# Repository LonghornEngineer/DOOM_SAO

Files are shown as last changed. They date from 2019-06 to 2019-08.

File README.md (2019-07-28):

### DOOM Shitty Add On Features
***
**Add on for conference badges that features a LCD Screen and DOOM Guy.**

The DOOM Shitty Add On (DOOM SAO) is an add on for conference badges that implement the [V1.69bis standard](https://hackaday.com/2019/03/20/introducing-the-shitty-add-on-v1-69bis-standard/) for SAO devices. Additionally, it has provisions to be a full on development platform for the ATSAMD21G18A microcontroller. The MCU and preinstalled bootloader are also Arduino compatible to aid in the ease of hardware and firmware hacking. This document will explain the feature set and how to interface with the DOOM SAO to bring out its full potential.

Doom SAO

## Full Feature Set
* Arduino Compatible MCU ATSAMD21G18A
* All unused I/O from the MCU is accessible
* Full implementation of the [V1.69bis standard](https://hackaday.com/2019/03/20/introducing-the-shitty-add-on-v1-69bis-standard/)
* Auto mode for DOOM Guy for badges that are not DOOM SAO compatible
* Serial Terminal accessible through the USB Type-C connector
* Passive Hardware Bus Sniffing
* User defined section for adding your own code
* High DPI ST7789 1.3" 240x240 LCD Screen
* USB Type-C configured for USB 2.0 (REVERSIBLE)

## Interfacing with the DOOM SAO via Serial UART

Connection Settings: 9600/8/N/1

Ensure your terminal terminates with Carriage Return (The Arduino Serial Monitor defaults to New Line. This is wrong)

Press 'X' to start the interactive menu.

Press 1..6 to select sub-menu options.

Press 'Q' within any sub-menu to quit to the main menu.

Menu Options:

1 - DOOM Guy Interface Mode
This allows you to modify the EEPROM directly to dynamically control the animations and SAO behavior.

2 - DOOM Guy Bus Sniffer Mode
This is a filtered view of the DOOM Guy's I2C traffic. It's a poor man's logic analyzer, decoded for SAO interpretation.

3 - I2C Bus Sniffer Mode
This allows you to monitor the entire I2C bus. If a host has more than one SAO port you can see what magic bytes and data other SAO's are transmitting in addtion to what the badge is using on I2C. It's a poor man's logic analyzer, decoded in general, for seeing I2C NACK, ACK, Reads, and Writes.

4 - Serial UART Sniffer Mode
This allows you to passively man in the middle another embedded system's serial UART line. 
Connect the source's serial TX to the SAO RX Pin PB23.
Connect the target's serial RX to the SAO TX Pin PB22.
Choose the appropriate baud rate and byte translation (ASCII or DEC).

5 - Custom  Application Mode
This is the area for YOU to add your own code.

6 - EEPROM Persistance Mode
This allows you to save changes made to the EEPROM, which by default reset on power cycle.

6 - BADGE SAO Airplane Mode
This allows you to ignore all logical control of the host badge. In minor cases, a badge may have a component which uses the same address (0x50) as our SAO, which will result in unexpected behavior. This is known to be the case with Team Ides DaBomb! Badge. In this case, enable persistance, enable airplane mode, then disable persistance so the SAO can still operate in a standalone mode. Not doing so will require reflashing of the SAO with the Arduino IDE.

## Interfacing with the DOOM SAO via I2C

The DOOM SAO implements the [V1.69bis standard](https://hackaday.com/2019/03/20/introducing-the-shitty-add-on-v1-69bis-standard/) for SAO devices and follows the [AND!XOR SAO Reference Design](https://github.com/ANDnXOR/sao-reference-designs). What this means is that using the I2C interface and GPIO pins of the V1.69bis standard users will be able to control how DOOM Guy acts and behaves.

The I2C address for DOOM SAO is 0x50. This is the standard address for the I2C AT24C32 EEPROM. Over the I2C interface, DOOM SAO acts like a simulated EEPROM. Only single byte reads and writes are supported. Attempting to do multi byte reads or writes are not implemented at this time. For identification purposes the first 3 address locations are used. See the [AND!XOR SAO Reference Design](https://github.com/ANDnXOR/sao-reference-designs) for more information. Below is the EEPROM address structure. 

| 0		| 1		| 2 	| 3...n	|
|:-:	|:-:	|:-:	|:-:	|
| 0x1B	| 0x05	| 0x01	| Data	|

* Address 0 is the DC Year. Use 0x1B for DC27.
* Address 1 is my Maker ID which is a unique identifier for SAO maker, I chose 0x05 at random for my maker ID. I do not know if there is a list of these ¯\_(ツ)_/¯.
* Address 2 is the SAO Type ID which is a unique identifier for the SAO. DOOM SAO is my only SAO so it is 0x01. 
* Addresss 3..n is where you can write stuff to the SAO!

First 3 addresses are protected and can not be overwritten unless you change them in the firmware and reflash the MCU.

### EEPROM Addresses

| Address	| Content	| Default Value	| Protected?	|
|:-:		|:-:		|:-:			|:-:			|
| 0x00		| DC Year	| 0x1B			| Yes			|
| 0x01		| Maker ID	| 0x05			| Yes			|
| 0x02		| SAO ID	| 0x01			| Yes			|
| 0x03		| AutoMode	| 0x01			| No			|
| 0x04		| Health	| 0x64			| No			|
| 0x05		| Anger	| 0x00			| No			|

### EEPROM functionality (quirks to note) 

Write functions to the DOOM SAO will always ACK regardless if you where successful or not in writing to that address location.
Reading data locations that do not exist will return with data 0x00. 

### What is Auto Mode?

When first booted up, DOOM SAO defaults to an auto mode. In this mode, Doom Guy looks left and right in an alternating manner with no control from the Badge. Writing a 0x00 value to this address disables auto mode and allows the GPIO to control DOOM Guy. With auto mode disabled, GPIO 1 makes DOOM Guy look left and GPIO 2 makes DOOM Guy look right. Truth table below.

| GPIO 1	| GPIO 2	| What Happens?			|
|:-:		|:-:		|:-:					|
| 0			| 0			| DG Looks Forward		|
| 1			| 0			| DG Looks Left			|
| 0			| 1			| DG Looks Right		|
| 1			| 1			| DG Looks Backwards	|

### What is Health?

The more "damage" Doom Guy takes the more beat up he becomes. Writing a value under 0x64 (100HP) will make Doom Guy look more bloody like he has been punched by a couple of demons. 

### What is Anger?

When Doom Guy gets pissed he gets pissed. Writing a 0x01 value to this location will seriously piss Doom Guy off. This must be his special spot. 

***
**License Information**

PROPRIETARY AND CONFIDENTIAL UNTIL AUGUST 11th, 2019 then,
Licensed under the Apache License, Version 2.0 (the "License");
you may not use this file except in compliance with the License.
You may obtain a copy of the License at
 
http://www.apache.org/licenses/LICENSE-2.0
 
Unless required by applicable law or agreed to in writing, software
distributed under the License is distributed on an "AS IS" BASIS,
WITHOUT WARRANTIES OR CONDITIONS OF ANY KIND, either express or implied.
See the License for the specific language governing permissions and
limitations under the License.
 
***

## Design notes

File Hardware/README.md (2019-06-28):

### DOOM Shitty Add On Hardware
***
**Add on for conference badges that features a LCD Screen and DOOM Guy.**

PCB was designed in AutoDesk Eagle V9.3+

## Hardware Specifications
* Arduino Compatible MCU ATSAMD21G18A
* Full implementation of the [V1.69bis standard](https://hackaday.com/2019/03/20/introducing-the-shitty-add-on-v1-69bis-standard/)
* High DPI ST7789 1.3" 240x240 LCD Screen
* USB Type-C configured for USB 2.0 (REVERSIBLE)
* TPS2113ADRBR Power Mux to prevent voltage back feed onto badge when USB power applied
* Tag Connect for ATMEL SWD Programming
* Unused GPIO from MCU broken out to headers
* Possibly the only 4 Layer SAO

## PCB Layers
1. Component mounting and signals
2. Ground
3. +3.3V
4. GPIO Breakout signals

## Schematic

Schematic DOOM SAO

## Board Layout

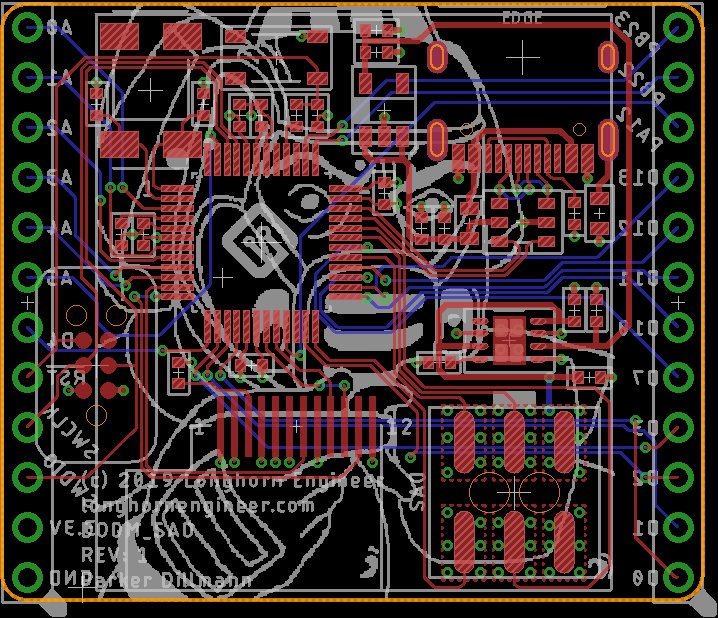
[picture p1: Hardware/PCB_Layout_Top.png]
Board Layout Top DOOM SAO


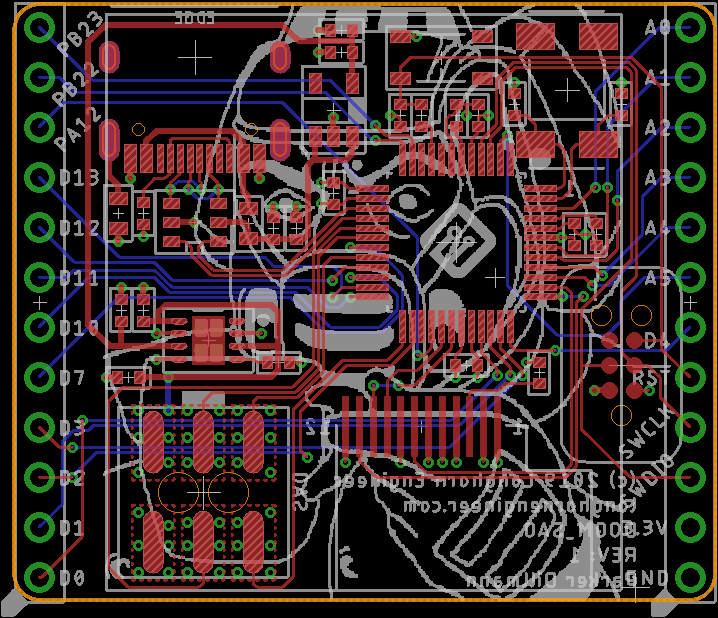
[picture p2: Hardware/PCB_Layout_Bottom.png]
Board Layout Bottom DOOM SAO


## PCB Render

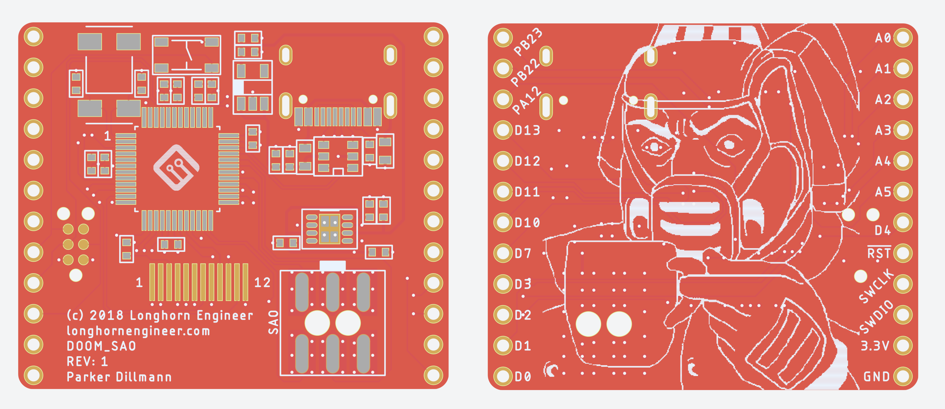
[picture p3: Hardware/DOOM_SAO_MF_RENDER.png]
PCB Render DOOM SAO


***
**License Information**

This project is under the [Creative Commons Attribution-ShareAlike 4.0 International License](LICENSE.md). These files are provided with no warranty and should be used at your own risk. 

***

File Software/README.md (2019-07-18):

### DOOM Shitty Add On Software 
***
**Add on for conference badges that features a LCD Screen and DOOM Guy.**

Software is written using the Arduino IDE 1.8.9. This document will explain how to setup the software environment to compile the firmware.

## Arduino Hardware Settings
* Board Manager Package: Arduino SAMD Boards (32-bits ARM Cortex-M0+) Version 1.8.2
* Board: Arduino M0

## Libraries
The following libraries need to be installed. These can be found through the Arduino Library Manager.

* Adafruit GFX Library Version 1.5.6
* Adafruit ST7735 and ST7789 Library Version 1.3.7
* Adafruit Zero DMA Library Version 1.0.4

## Modifying Libraries

To make these libraries work with the DOOM SAO Hardware some modifications must be made. 

In Windows these are located under *Documents\Arduino\libraries* if they were installed through the Arduino Library Manager.

In Ubuntu Linux these are located under *$HOME/Arduino/libraries* if they were installed through the Arduino Library Manager.

### Enabling SPI_MODE3
Since the hardware does not use the CS pin on the LCD we must change the GFX library from using SPI_MODE0 to SPI_MODE3. 

Open the *\Adafruit_GFX_Library\Adafruit_SPITFT.h* file
Change SPI_MODE0 in line 193 to SPI_MODE3
Save the file

Open the *\Adafruit_ST7735_and_ST7789_Library\Adafruit_ST7789.h* file
Change SPI_MODE0 in line 17 to SPI_MODE3
Save the file

### Enable DMA
In the GFX library the hardware DMA is not enabled by default and must be turned on.

Open the *\Adafruit_GFX_Library\Adafruit_SPITFT.h* file.
Uncomment Line 77 which reads *#define USE_SPI_DMA               ///< If set, use DMA if available*
Save the file

The DOOM_SAO.ino file should compile correctly in the Arduino IDE now. 

***

**License Information**

PROPRIETARY AND CONFIDENTIAL UNTIL AUGUST 11th, 2019 then,
Licensed under the Apache License, Version 2.0 (the "License");
you may not use this file except in compliance with the License.
You may obtain a copy of the License at
 
http://www.apache.org/licenses/LICENSE-2.0
 
Unless required by applicable law or agreed to in writing, software
distributed under the License is distributed on an "AS IS" BASIS,
WITHOUT WARRANTIES OR CONDITIONS OF ANY KIND, either express or implied.
See the License for the specific language governing permissions and
limitations under the License.
 
***

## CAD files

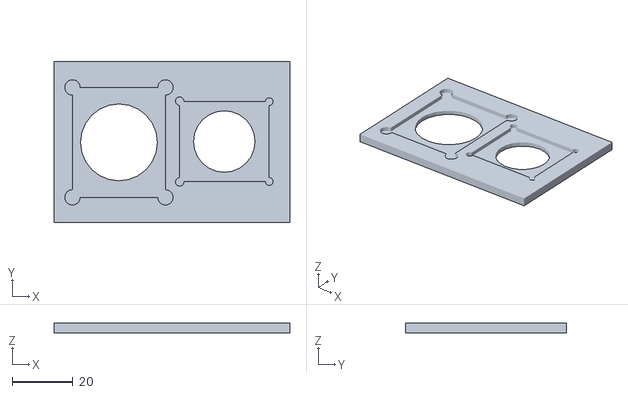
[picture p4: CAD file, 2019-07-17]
Hardware/Soldering_Fixture.stl
78.0 x 53.3 x 3.17

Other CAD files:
Hardware/Soldering_Fixture.skp

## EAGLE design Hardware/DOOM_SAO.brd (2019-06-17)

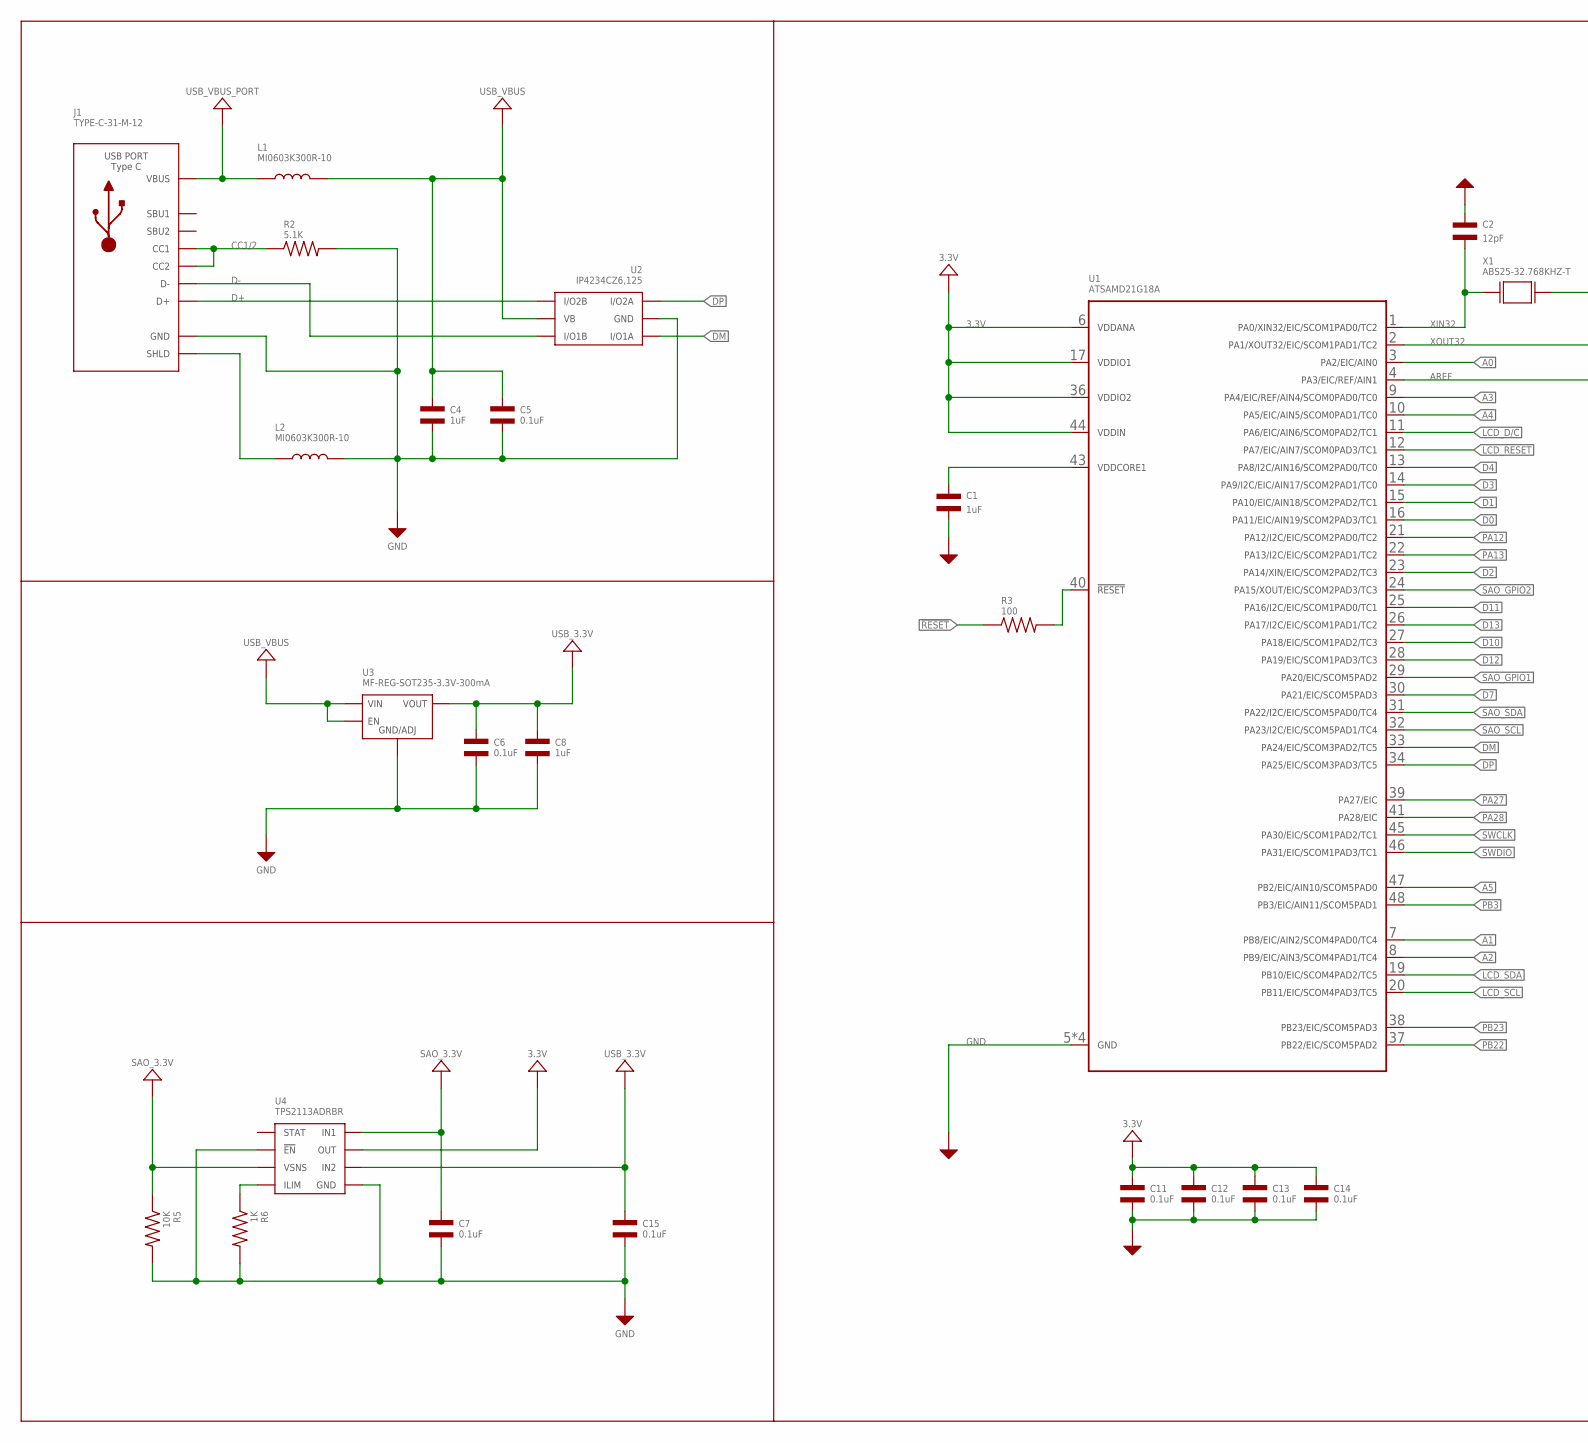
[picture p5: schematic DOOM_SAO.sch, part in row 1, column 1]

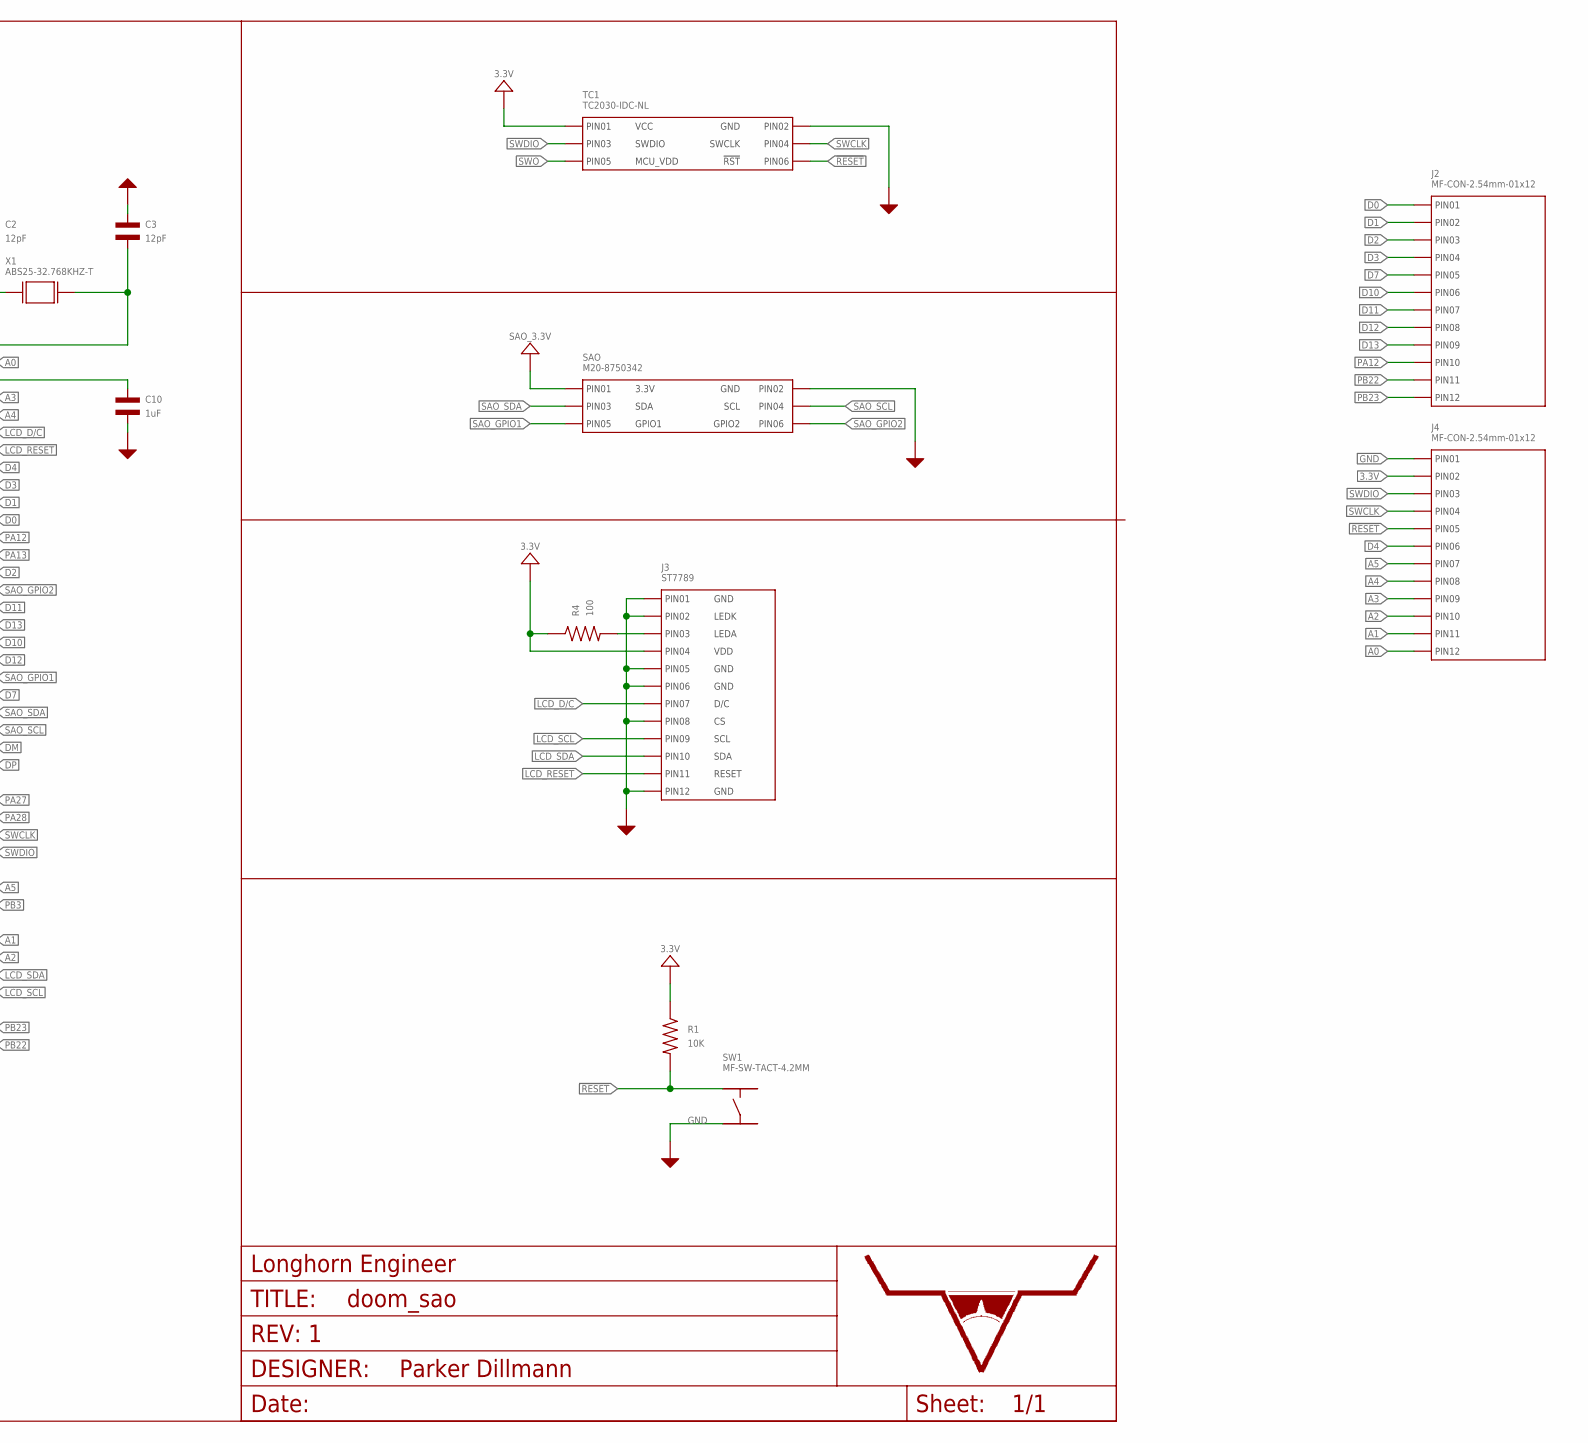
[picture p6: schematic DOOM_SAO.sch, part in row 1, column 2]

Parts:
C1, C4, C8, C10: 1uF; C0402; MPN MF-CAP-0402-1uF
C2, C3: 12pF; C0402; MPN CC0402JRNPO9BN120
C5, C6, C7, C11, C12, C13, C14, C15: 0.1uF; C0402; MPN MF-CAP-0402-0.1uF
J1: TYPE-C-31-M-12; MPN TYPE-C-31-M-12
J2, J4: MF-CON-2.54mm-01x12; PTH_2.54MM_01X12
J3: ST7789; ST7789_CONNECTOR
L1, L2: MI0603K300R-10; L0603; MPN MI0603K300R-10
R1, R5: 10K; R0402; MPN MF-RES-0402-10K
R2: 5.1K; R0402; MPN ERJ-2RHD5101X
R3, R4: 100; R0402; MPN MF-RES-0402-100
R6: 1K; R0402; MPN MF-RES-0402-1K
SAO: M20-8750342; MPN M20-8750342
SW1: MF-SW-TACT-4.2MM; TACT4.2MM
TC1: TC2030-IDC-NL
U1: ATSAMD21G18A; ATSAMD21G18A_TQFP-48; MPN ATSAMD21G18A-AU
U2: IP4234CZ6,125; IP4234CZ6_SOT-457-6; MPN IP4234CZ6,125
U3: MF-REG-SOT235-3.3V-300mA; SOT-23-5
U4: TPS2113ADRBR; TPS211X_SON-8
U$8: LHE_FRAME
X1: ABS25-32.768KHZ-T; ABS25_SERIES; MPN ABS25-32.768KHZ-T

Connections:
3.3V: C11.P$1, C12.P$1, C13.P$1, C14.P$1, J3.P$4 (4), J4.P$2 (PIN2), R1.P$1, R4.P$1, TC1.P$1 (PIN1), U1.6 (VDDANA), U1.17 (VDDIO1), U1.36 (VDDIO2), U1.44 (VDDIN), U4.7 (OUT)
!RESET: J4.P$5 (PIN5), R1.P$2, R3.P$1, SW1.P$1, TC1.P$6 (PIN6)
A0: J4.P$12 (PIN12), U1.3 (PA2/EIC/AIN0)
A1: J4.P$11 (PIN11), U1.7 (PB8/EIC/AIN2/SCOM4PAD0/TC4)
A2: J4.P$10 (PIN10), U1.8 (PB9/EIC/AIN3/SCOM4PAD1/TC4)
A3: J4.P$9 (PIN9), U1.9 (PA4/EIC/REF/AIN4/SCOM0PAD0/TC0)
A4: J4.P$8 (PIN8), U1.10 (PA5/EIC/AIN5/SCOM0PAD1/TC0)
A5: J4.P$7 (PIN7), U1.47 (PB2/EIC/AIN10/SCOM5PAD0)
AREF: C10.P$1, U1.4 (PA3/EIC/REF/AIN1)
BK_LIGHT: J3.P$3 (3), R4.P$2
CC1/2: J1.A5 (CC1), J1.B5 (CC2), R2.P$1
D0: J2.P$1 (PIN1), U1.16 (PA11/EIC/AIN19/SCOM2PAD3/TC1)
D1: J2.P$2 (PIN2), U1.15 (PA10/EIC/AIN18/SCOM2PAD2/TC1)
D2: J2.P$3 (PIN3), U1.23 (PA14/XIN/EIC/SCOM2PAD2/TC3)
D3: J2.P$4 (PIN4), U1.14 (PA9/I2C/EIC/AIN17/SCOM2PAD1/TC0)
D4: J4.P$6 (PIN6), U1.13 (PA8/I2C/AIN16/SCOM2PAD0/TC0)
D7: J2.P$5 (PIN5), U1.30 (PA21/EIC/SCOM5PAD3)
D10: J2.P$6 (PIN6), U1.27 (PA18/EIC/SCOM1PAD2/TC3)
D11: J2.P$7 (PIN7), U1.25 (PA16/I2C/EIC/SCOM1PAD0/TC1)
D12: J2.P$8 (PIN8), U1.28 (PA19/EIC/SCOM1PAD3/TC3)
D13: J2.P$9 (PIN9), U1.26 (PA17/I2C/EIC/SCOM1PAD1/TC2)
D+: J1.A6 (D+), J1.B6 (D+), U2.4 (I/O2B)
D-: J1.A7 (D-), J1.B7 (D-), U2.3 (I/O1B)
DM: U1.33 (PA24/EIC/SCOM3PAD2/TC5), U2.1 (I/O1A)
DP: U1.34 (PA25/EIC/SCOM3PAD3/TC5), U2.6 (I/O2A)
GND: C1.P$2, C2.P$1, C3.P$1, C4.P$2, C5.P$2, C6.P$2, C7.P$2, C8.P$2, C10.P$2, C11.P$2, C12.P$2, C13.P$2, C14.P$2, C15.P$2, J1.A1/B12 (GND), J1.B1/A12 (GND), J3.P$1 (1), J3.P$2 (2), J3.P$5 (5), J3.P$6 (6), J3.P$8 (8), J3.P$12 (12), J4.P$1 (PIN1), L2.P$2, R2.P$2, R5.P$2, R6.P$2, SAO.2 (PIN2), SW1.P$3, TC1.P$2 (PIN2), U1.5 (GND), U1.18 (GND), U1.35 (GND), U1.42 (GND), U2.2 (GND), U3.P$2 (GND/ADJ), U4.2 (!EN), U4.5 (GND), U4.PAD (GND)
LCD_D/C: J3.P$7 (7), U1.11 (PA6/EIC/AIN6/SCOM0PAD2/TC1)
LCD_RESET: J3.P$11 (11), U1.12 (PA7/EIC/AIN7/SCOM0PAD3/TC1)
LCD_SCL: J3.P$9 (9), U1.20 (PB11/EIC/SCOM4PAD3/TC5)
LCD_SDA: J3.P$10 (10), U1.19 (PB10/EIC/SCOM4PAD2/TC5)
PA12: J2.P$10 (PIN10), U1.21 (PA12/I2C/EIC/SCOM2PAD0/TC2)
PA13: U1.22 (PA13/I2C/EIC/SCOM2PAD1/TC2)
PA27: U1.39 (PA27/EIC)
PA28: U1.41 (PA28/EIC)
PB3: U1.48 (PB3/EIC/AIN11/SCOM5PAD1)
PB22: J2.P$11 (PIN11), U1.37 (PB22/EIC/SCOM5PAD2)
PB23: J2.P$12 (PIN12), U1.38 (PB23/EIC/SCOM5PAD3)
RESETLIN: R3.P$2, U1.40 (!RESET)
SAO_3.3V: C7.P$1, R5.P$1, SAO.1 (PIN1), U4.3 (VSNS), U4.8 (IN1)
SAO_GPIO1: SAO.5 (PIN5), U1.29 (PA20/EIC/SCOM5PAD2)
SAO_GPIO2: SAO.6 (PIN6), U1.24 (PA15/XOUT/EIC/SCOM2PAD3/TC3)
SAO_SCL: SAO.4 (PIN4), U1.32 (PA23/I2C/EIC/SCOM5PAD1/TC4)
SAO_SDA: SAO.3 (PIN3), U1.31 (PA22/I2C/EIC/SCOM5PAD0/TC4)
SHLD: J1.MT_B_0 (SHLD), J1.MT_B_1 (SHLD), J1.MT_B_2 (SHLD), J1.MT_B_3 (SHLD), J1.MT_T_0 (SHLD), J1.MT_T_1 (SHLD), J1.MT_T_2 (SHLD), J1.MT_T_3 (SHLD), L2.P$1
SWCLK: J4.P$4 (PIN4), TC1.P$4 (PIN4), U1.45 (PA30/EIC/SCOM1PAD2/TC1)
SWDIO: J4.P$3 (PIN3), TC1.P$3 (PIN3), U1.46 (PA31/EIC/SCOM1PAD3/TC1)
SWO: TC1.P$5 (PIN5)
TPS_ILIM: R6.P$1, U4.4 (ILIM)
USB_3.3V: C6.P$1, C8.P$1, C15.P$1, U3.P$5 (VOUT), U4.6 (IN2)
USB_VBUS: C4.P$1, C5.P$1, L1.P$2, U2.5 (VB), U3.P$1 (VIN), U3.P$3 (EN)
USB_VBUS_PORT: J1.A4/B9 (VBUS), J1.B4/A9 (VBUS), L1.P$1
VDDCORE: C1.P$1, U1.43 (VDDCORE1)
XIN32: C2.P$2, U1.1 (PA0/XIN32/EIC/SCOM1PAD0/TC2), X1.1 (X0)
XOUT32: C3.P$2, U1.2 (PA1/XOUT32/EIC/SCOM1PAD1/TC2), X1.4 (X1)

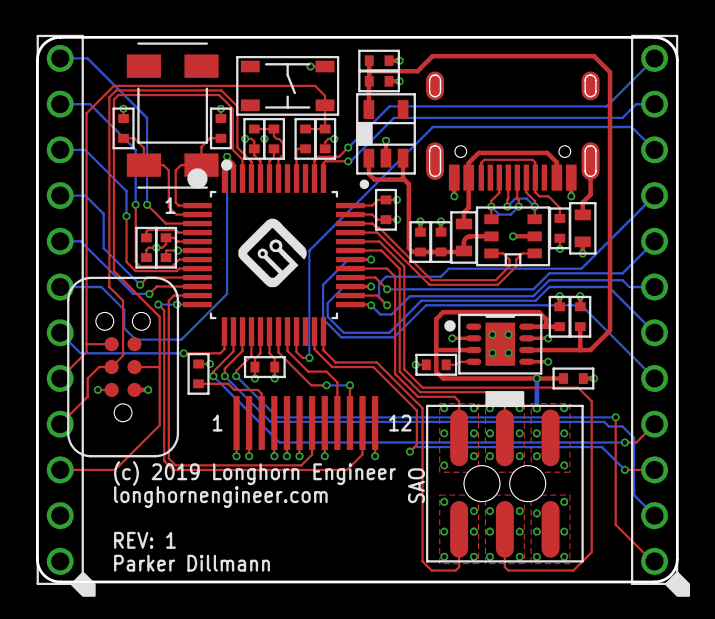
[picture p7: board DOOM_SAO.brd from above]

Board: 4 copper layers, 35.6 x 30.3 mm, 36 parts (0 on the bottom side), 49 nets.

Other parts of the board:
U$9: MF_LOGO_SMALL

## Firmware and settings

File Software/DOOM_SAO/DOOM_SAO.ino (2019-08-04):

/*****************************************************************************
 * Made with beer and late nights in California and Texas.
 *
 * (C) Copyright 2017-2019 AND!XOR LLC (https://andnxor.com/).
 *
 * PROPRIETARY AND CONFIDENTIAL UNTIL AUGUST 11th, 2019 then,
 *
 * Licensed under the Apache License, Version 2.0 (the "License");
 * you may not use this file except in compliance with the License.
 * You may obtain a copy of the License at
 *
 *     http://www.apache.org/licenses/LICENSE-2.0
 *
 * Unless required by applicable law or agreed to in writing, software
 * distributed under the License is distributed on an "AS IS" BASIS,
 * WITHOUT WARRANTIES OR CONDITIONS OF ANY KIND, either express or implied.
 * See the License for the specific language governing permissions and
 * limitations under the License.
 *
 * ADDITIONALLY:
 * If you find this source code useful in anyway, use it in another electronic
 * conference badge, or just think it's neat. Consider buying us a beer
 * (or two) and/or a badge (or two). We are just as obsessed with collecting
 * badges as we are in making them.
 *
 * Contributors:
 *  @Cr4bf04m
 *  @andnxor
 *  @zappbrandnxor
 *  @hyr0n1
 *  @bender_andnxor
 *  @lacosteaef
 *  @f4nci3
 ****************************************************************************
 */
 
#include <Adafruit_GFX.h>   
#include <Adafruit_ST7789.h> 
#include <Wire.h>
#include "FlashStorage.h"
#include "DG_Faces.h"
#include "MF_Logo.h"

#define TFT_CS        -1
#define TFT_RST        9
#define TFT_DC         8
#define GPIO1          6 
#define GPIO2          5
#define SAOSERIAL      Serial 

#define SAMPLE            (REG_PORT_IN0 & (PORT_PA22 | PORT_PA23))
#define START1            (PORT_PA22 | PORT_PA23)
#define START2             PORT_PA23

#define BUFFSIZE          5000
#define TIMEOUT           1000

uint32_t buffer[BUFFSIZE];

int16_t dg_offset_x = 16;
int16_t dg_offset_y = 0;
int16_t dg_pixel_size = 8;
int16_t dg_rez_x = 26;

int16_t mf_offset_x = 0;
int16_t mf_offset_y = 0;
int16_t mf_pixel_size = 4;
int16_t mf_rez_x = 60;

uint8_t automode_cycle = 0x00;
uint8_t cycle = 0x00;
uint8_t mem_write_address = 0x00;
uint8_t mem_write_address_valid = 0x00;

// Simulated EEPROM address and storage!
//  Address | Content
//  0x00    | DC Year
//  0x01    | Maker ID
//  0x02    | SAO ID
//  0x03    | AutoMode
//  0x04    | Health
//  0x05    | Anger
uint8_t eeprom[6] = 
{
  0x1B, 0x05, 0x01, 0x01, 0x64, 0x00
};

// Create a structure to store our virtual EEPROM data to internal program flash
typedef struct
{
  // This by default will be false and set the first time the SAO is powered up
  bool init;        
  bool m6_persistence; 
  bool m7_airplane;
  // We don't store eeprom 0..2 because they are protected anyway
  uint8_t eeprom_3; 
  uint8_t eeprom_4;
  uint8_t eeprom_5;
} sao_data;

long previous_write_time = 0;

// Instanciate the flash store
FlashStorage(sao_flash_store, sao_data);
sao_data data;

bool menu_display_start = true;
bool menu_display_0 = false;
bool menu_display_1 = true;
bool menu_display_1_1 = true;
bool menu_display_2 = true;
bool menu_display_3 = true;
bool menu_display_4 = true;
bool menu_display_4_1 = true;
bool menu_display_5 = true;
bool menu_display_6 = true;
bool menu_display_7 = true;

bool sao_god_mode_display = false;
uint8_t sao_mode = 0;
uint8_t incomingByte = 0;

uint8_t m1_interface_addr = 0;
uint8_t m1_interface_value = 0;
int m1_char_count = 0;
int m1_inChar = 0;
int m1_inconspicuous_variable = 0;
int m1_lowkey_variable = 0;
bool m1_interface_addr_selection = false;
bool m1_interface_value_selection = false;
String m1_inString = ""; 

bool m4_hw_baud_selection = false;
uint8_t m4_hw_translation_mode = 0;
uint8_t m4_hw_incoming_byte = 0;

bool m6_persistence = false;
bool m6_persistence_init_test = false;

bool m7_airplane = false;

Adafruit_ST7789 tft = Adafruit_ST7789(TFT_CS, TFT_DC, TFT_RST);

void macro_splash()
{
  SerialUSB.println(" ");
  SerialUSB.println("***********************************************************");
  SerialUSB.println(" ");
  SerialUSB.println("    DC27 DOOM SAO - SAMD21 Arduino Compatible Dev Board");
  SerialUSB.println(" ");
  SerialUSB.println("                         ▓▓▓▓▓▓▓▓▓                         ");
  SerialUSB.println("                       ▓▓▓▓▓▓▓▓▓▓▓▓▓                       ");
  SerialUSB.println("                     ▓▓▓▓▓▓▓▓▓▓▓▓▓▓▓▓▓                     ");
  SerialUSB.println("                   ▓▓▓▓▓▓▓▓▓▓▓▓▓▓▓▓▓▓▓▓▓                   ");
  SerialUSB.println("                 ▓▓▓▓▓▓▓▓▓▓▓   ▓▓▓▓▓▓▓▓▓▓▓                 ");
  SerialUSB.println("               ▓▓▓▓▓▓▓▓▓▓▓       ▓▓▓▓▓▓▓▓▓▓▓               ");
  SerialUSB.println("             ▓▓▓▓▓▓▓▓▓▓▓           ▓▓▓▓▓▓▓▓▓▓▓             ");
  SerialUSB.println("           ▓▓▓▓▓▓▓▓▓▓▓               ▓▓▓▓▓▓▓▓▓▓▓           ");
  SerialUSB.println("         ▓▓▓▓▓▓▓▓▓▓▓                   ▓▓▓▓▓▓▓▓▓▓▓         ");
  SerialUSB.println("       ▓▓▓▓▓▓▓▓▓▓▓▒          ▓▓▓▓▓▓▓     ▓▓▓▓▓▓▓▓▓▓▓       ");
  SerialUSB.println("     ▓▓▓▓▓▓▓▓▓▓▓           ▓▓▓▓   ▓▓▓▓     ▓▓▓▓▓▓▓▓▓▓▓     ");
  SerialUSB.println("   ▓▓▓▓▓▓▓▓▓▓▓             ▓▓▒     ▓▓▓       ▓▓▓▓▓▓▓▓▓▓▓   ");
  SerialUSB.println(" ▓▓▓▓▓▓▓▓▓▓▓               ▓▓▓     ▓▓▓         ▓▓▓▓▓▓▓▓▓▓▓ ");
  SerialUSB.println("▓▓▓▓▓▓▓▓▓▓        ▓▓▓▓▓▓    ▓▓▓▓▓▓▓▓▓▓▓          ▓▓▓▓▓▓▓▓▓▓");
  SerialUSB.println("▓▓▓▓▓▓▓▓         ▓▓▒  ▓▓▓          ▓▓▓▓▓▓          ▓▓▓▓▓▓▓▓");
  SerialUSB.println("▓▓▓▓▓▓▓▓         ▓▓   ▒▓▓            ▓▓▓▓▓▓          ▓▓▓▓▓▓");
  SerialUSB.println("▓▓▓▓▓▓▓▓▓▓        ▓▓▓▓▓▓▓▓▒            ▓▓▓▓▓▓          ▓▓▓▓");
  SerialUSB.println("  ▓▓▓▓▓▓▓▓▓▓          ▒▓▓▓▓▓▒           ▒▓▓▓▓▓▓         ▓▓ ");
  SerialUSB.println("    ▓▓▓▓▓▓▓▓▓▓          ▒▓▓▓▓▓▒           ▒▓▓▓▓▓▓          ");
  SerialUSB.println("      ▓▓▓▓▓▓▓▓▓▓          ▒▓▓▓▓▓▒           ▓▓▓▓▓▓▓        ");
  SerialUSB.println("        ▓▓▓▓▓▓▓▓▓▓           ▓▓▓▓▓▓       ▓▓▓▓▓▓▓▓▓        ");
  SerialUSB.println("          ▓▓▓▓▓▓▓▓▓▓           ▓▓▓▓▓▓   ▓▓▓▓▓▓▓▓▓          ");
  SerialUSB.println("            ▓▓▓▓▓▓▓▓▓▓           ▓▓▓▓▓▓▓▓▓▓▓▓▓▓            ");
  SerialUSB.println("              ▓▓▓▓▓▓▓▓▓▓           ▓▓▓▓▓▓▓▓▓▓              ");
  SerialUSB.println("                ▓▓▓▓▓▓▓▓▓▓       ▓▓▓▓▓▓▓▓▓▓                ");
  SerialUSB.println("                  ▓▓▓▓▓▓▓▓▓▓▒ ▒▓▓▓▓▓▓▓▓▓▓                  ");
  SerialUSB.println("                    ▓▓▓▓▓▓▓▓▓▓▓▓▓▓▓▓▓▓▓                    ");
  SerialUSB.println("                      ▓▓▓▓▓▓▓▓▓▓▓▓▓▓▓▒                     ");
  SerialUSB.println("                        ▓▓▓▓▓▓▓▓▓▓▓▒                       ");
  SerialUSB.println(" ");
  SerialUSB.println("***********************************************************");
  SerialUSB.println(" ");
  SerialUSB.flush();
}

void persist_eeprom()
{
  sao_flash_store.write(data);
  return;
}

// This function converts integers to hex for pretty printing  
void printHex(int num, int precision)
{
  char tmp[16];
  char format[128];
  sprintf(format, "0x%%.%dX", precision);
  sprintf(tmp, format, num);
  SerialUSB.print(tmp);
  return;
}

void mode_1_dg_interface()
{
  if(menu_display_1)
  {
    SerialUSB.println("\n**DOOM Guy Interface Mode**");
    SerialUSB.println("Press Q to quit back to the main menu");  
    SerialUSB.println("For details visit ~ https://github.com/LonghornEngineer/DOOM_SAO");
    SerialUSB.println("-----------------------------------------------------------------");  
    SerialUSB.println("|EEPROM ADDRESS|    0 |    1 |    2 |    3 |    4 |    5 | 6..n |");
    SerialUSB.println("-----------------------------------------------------------------");
    SerialUSB.print("|CURRENT  VALUE| ");
    for(int i = 0; i < 6; i++){
      printHex(eeprom[i],2);  
      SerialUSB.print(" | ");
    }
    SerialUSB.println("???? |");    
    SerialUSB.println("-----------------------------------------------------------------");
    SerialUSB.println("|DEFAULT  VALUE| 0x1B | 0x05 | 0x01 | 0x01 | 0x64 | 0x00 | ???? |");
    SerialUSB.println("-----------------------------------------------------------------");
    SerialUSB.println("*Address 0..2 Are Protected");
    SerialUSB.println("*Address 3 is AutoMode Toggle");
    SerialUSB.println("*Address 4 is Health");
    SerialUSB.println("*Address 5 is Anger");
    SerialUSB.println("*Address 6..255 Are Sekret Data");
    SerialUSB.print("Please select your target address (3..255): ");
    menu_display_1 = false; //this prevents infinite printing of the menu in loop   
  }

  if((m1_interface_addr_selection) && (!m1_interface_value_selection) && (menu_display_1_1) && (!menu_display_1))
  {
    SerialUSB.print("Please enter the new value for this address in decimal (255 max): ");
    menu_display_1_1 = false;
  }

  // Clear the Buffers
  if(m1_inString[m1_char_count] == '\r')
  {
    m1_inString = ""; // clear the buffer for new input if they hit return
    m1_char_count = 0;
  }

  // This parses the input for ASCII numbers, charachters will be ignored (except Q or q for Quit)
  while (SerialUSB.available() > 0)
  {
    m1_inChar = SerialUSB.read();
    if (isAlpha(m1_inChar))
    {
      if(((char)m1_inChar == 'q') || ((char)m1_inChar == 'Q'))
      {
        // Press (Q or q) to quit back to main menu
        SerialUSB.print((char)m1_inChar); //echo user selection to the USB terminal
        SerialUSB.println(" \n"); 
        sao_mode = 0;
        menu_display_0 = true;
        menu_display_1 = true;
        menu_display_1_1 = true;
        break;      
      }
    }
    
    if (isDigit(m1_inChar))
    {
      // convert the incoming byte to a char and add it to the string if it happens to be a digit
      m1_inString += (char)m1_inChar;
      m1_char_count++;
    }
    
    if ((m1_inChar == '\r') && (m1_inString.length() > 0))
    {
      // if you get a carrige return, parse the input
      if(!m1_interface_addr_selection)
      {
        // Assign the address
        if(m1_inString.toInt() <= 255)
          m1_interface_addr = m1_inString.toInt();
        else
          m1_interface_addr = 255;
        
        m1_interface_addr_selection = true;
        //Echo User Input to the Terminal
        SerialUSB.println(m1_inString);
      }
      else if((m1_interface_addr_selection)&&(!m1_interface_value_selection))
      {
        // Assign the value
        if(m1_inString.toInt() <= 255)
          m1_interface_value = m1_inString.toInt();
        else
          m1_interface_value = 255;
        m1_interface_value_selection = true;
        // Echo User Input to the Terminal
        SerialUSB.println(m1_inString);
      }
      
      if((m1_interface_addr_selection)&&(m1_interface_value_selection))
      {           
        // Update the EEPROM
        write_to_eeprom(m1_interface_addr, m1_interface_value);
        
        // Reset Variables so the interactive menu appears again
        m1_interface_addr_selection = false;
        m1_interface_value_selection = false;
        menu_display_1 = true;
        menu_display_1_1 = true;
        m1_char_count = 0;
      }
      // clear the buffer for new input
      m1_inString = ""; 
    }
  }    
}

void mode_2_dg_sniffer()
{
  if(menu_display_2)
  {
    SerialUSB.println("**DOOM Guy Bus Sniffer Mode**");
    if(m7_airplane) SerialUSB.println("Currently in Airplane Mode - You Won't See Anything!");
    SerialUSB.println("Press Q to quit back to the main menu.\n");  
    // this prevents infinite printing of the menu in loop 
    menu_display_2 = false;   
  }
  // Press (Q or q) to quit back to main menu
  incomingByte = SerialUSB.read();
  if((incomingByte == 'q') || (incomingByte == 'Q'))
  {
    sao_mode = 0;
    menu_display_0 = true;
    menu_display_2 = true;
    SerialUSB.println(" \n");
  }
}

//////////////////////////
// i2c sniffer based off the code by rricharz
// https://github.com/rricharz/i2c-sniffer-100kBaud-Arduino-Mega
// Rene Richarz if you are out there. I will buy you all the beer! @Cr4bf04m
//////////////////////////

void mode_3_i2c_sniffer()
{
  if(menu_display_3)
  {
    SerialUSB.println("**I2C SAO Bus Sniffer**");
    SerialUSB.println("Based off code by rricharz");
    SerialUSB.print("Press Q to quit back to the main menu: ");  
    // this prevents infinite printing of the menu in loop   
    menu_display_3 = false; 
  }
  // Press (Q or q) to quit back to main menu
  incomingByte = SerialUSB.read();
  if((incomingByte == 'q') || (incomingByte == 'Q'))
  {
    // echo user selection to the USB terminal
    SerialUSB.print((char)incomingByte); 
    SerialUSB.println(" \n");
    sao_mode = 0;
    menu_display_0 = true;
    menu_display_3 = true;
  }
  int points = acquire_data();
  display_data(points);
}
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
void loop()
{
  // Default mode - DG Face Mode
  // Assumption is this mode is normally just "plugged into a badge"
  // If Auto mode: DG looks around 
  // If Badge Control mode: DG looks around depending on the state of GPIO 1/2
  // Depending on the heath value of the EEPROM DG will be more bloody!
  // Depending on the anger value of the EEPROM DG might be well....
  if(sao_mode < 2)
  {
    menu();
    // Automode ENABLED!
    if(eeprom[3] == 1)
    {
      automode_cycle++;
      if(automode_cycle > 3)
      {
        automode_cycle = 0;
      }
      cycle = automode_cycle;
    }
    // Automode Disabled! ASSUMING DIRECT BADGE CONTROL!
    else
    {
      // Look Forward
      if (digitalRead(GPIO1) == 0 && digitalRead(GPIO2) == 0)
      {
        cycle = 1;
      }
      // Look Left
      else if (digitalRead(GPIO1) == 1 && digitalRead(GPIO2) == 0)
      {
        cycle = 0;
      }
      // Look Right
      else if (digitalRead(GPIO1) == 0 && digitalRead(GPIO2) == 1)
      {
        cycle = 2;
      }
      // Whut?!
      else
      {
        cycle = 3;
      }
    }
    run_sao_mode_0(cycle);
    delay(500);
  }
  
  // It is better to disable the animation and the delays so they have real time control of the MCU.
  // Appropriately just display God Mode in this case.
  // There is a boolean toggle because it wastes time to continually redraw the same image
  else
  {  
    if(sao_god_mode_display) 
    {
      render(dg_god_mode, sizeof(dg_god_mode)/2, dg_offset_x, dg_offset_y, dg_pixel_size, dg_rez_x);
      sao_god_mode_display = false;
    }
    menu();
  }
}

void run_sao_mode_0(uint8_t face_dir)
{
  // DG Happy!
  if(eeprom[5] == 0)
  {
    if(m1_inconspicuous_variable == 1)
    {
      if(face_dir == 0)
      {
        render(bender_FullHP_left, sizeof(bender_FullHP_left)/2, mf_offset_x, mf_offset_y, mf_pixel_size, mf_rez_x);
      }
      else if(face_dir == 1)
      {
        render(bender_FullHP_middle, sizeof(bender_FullHP_middle)/2, mf_offset_x, mf_offset_y, mf_pixel_size, mf_rez_x);
      }
      else if(face_dir == 2)
      {
        render(bender_FullHP_right, sizeof(bender_FullHP_right)/2, mf_offset_x, mf_offset_y, mf_pixel_size, mf_rez_x);
      }
      else
      {
        render(bender_FullHP_middle, sizeof(bender_FullHP_middle)/2, mf_offset_x, mf_offset_y, mf_pixel_size, mf_rez_x);
      }
    }
    else if(m1_lowkey_variable == 1)
    {
      render(dg_dealwithit, sizeof(dg_dealwithit)/2, dg_offset_x, dg_offset_y, dg_pixel_size, dg_rez_x);
    }
    // DG Health 61
    else if(eeprom[4] == 0x3D)
    {
      if(face_dir == 0)
      {
        render(duke_FullHP_left, sizeof(duke_FullHP_left)/2, dg_offset_x, dg_offset_y, dg_pixel_size, dg_rez_x);
      }
      else if(face_dir == 1)
      {
        render(duke_FullHP_middle, sizeof(duke_FullHP_middle)/2, dg_offset_x, dg_offset_y, dg_pixel_size, dg_rez_x);
      }
      else if(face_dir == 2)
      {
        render(duke_FullHP_right, sizeof(duke_FullHP_right)/2, dg_offset_x, dg_offset_y, dg_pixel_size, dg_rez_x);
      }
      else if(eeprom[3] == 0)
      {
        render(duke_FullHP_cigar, sizeof(duke_FullHP_cigar)/2, dg_offset_x, dg_offset_y, dg_pixel_size, dg_rez_x);
      }
      else
      {
        render(duke_FullHP_middle, sizeof(duke_FullHP_middle)/2, dg_offset_x, dg_offset_y, dg_pixel_size, dg_rez_x);
      }
    }
    else if(eeprom[4] >= 0x50)
    {
      if(face_dir == 0)
      {
        render(dg_FullHP_left, sizeof(dg_FullHP_left)/2, dg_offset_x, dg_offset_y, dg_pixel_size, dg_rez_x);
      }
      else if(face_dir == 1)
      {
        render(dg_FullHP_middle, sizeof(dg_FullHP_middle)/2, dg_offset_x, dg_offset_y, dg_pixel_size, dg_rez_x);
      }
      else if(face_dir == 2)
      {
        render(dg_FullHP_right, sizeof(dg_FullHP_right)/2, dg_offset_x, dg_offset_y, dg_pixel_size, dg_rez_x);
      }
      else if(eeprom[3] == 0)
      {
        render(dg_bald, sizeof(dg_bald)/2, dg_offset_x, dg_offset_y, dg_pixel_size, dg_rez_x);
      }
      else
      {
        render(dg_FullHP_middle, sizeof(dg_FullHP_middle)/2, dg_offset_x, dg_offset_y, dg_pixel_size, dg_rez_x);
      }
    }
    // DG Health 60 or higher
    else if(eeprom[4] >= 0x3C)
    {
      if(face_dir == 0)
      {
        render(dg_80HP_left, sizeof(dg_80HP_left)/2, dg_offset_x, dg_offset_y, dg_pixel_size, dg_rez_x);
      }
      else if(face_dir == 1)
      {          
        render(dg_80HP_middle, sizeof(dg_80HP_middle)/2, dg_offset_x, dg_offset_y, dg_pixel_size, dg_rez_x);
      }
      else if(face_dir == 2)
      {
        render(dg_80HP_right, sizeof(dg_80HP_right)/2, dg_offset_x, dg_offset_y, dg_pixel_size, dg_rez_x);
      }
      else
      {
        render(dg_80HP_middle, sizeof(dg_80HP_middle)/2, dg_offset_x, dg_offset_y, dg_pixel_size, dg_rez_x);
      }
    }
    // DG Health 40 or higher
    else if(eeprom[4] >= 0x28)
    {    
      if(face_dir == 0)
      {      
        render(dg_60HP_left, sizeof(dg_60HP_left)/2, dg_offset_x, dg_offset_y, dg_pixel_size, dg_rez_x);
      }
      else if(face_dir == 1)
      {
        render(dg_60HP_middle, sizeof(dg_60HP_middle)/2, dg_offset_x, dg_offset_y, dg_pixel_size, dg_rez_x);
      }
      else if(face_dir == 2)
      {
        render(dg_60HP_right, sizeof(dg_60HP_right)/2, dg_offset_x, dg_offset_y, dg_pixel_size, dg_rez_x);
      }
      else
      {
        render(dg_60HP_middle, sizeof(dg_60HP_middle)/2, dg_offset_x, dg_offset_y, dg_pixel_size, dg_rez_x);
      }
    }
    // DG Health 20 or higher
    else if(eeprom[4] >= 0x14)
    {
      if(face_dir == 0)
      {
        render(dg_40HP_left, sizeof(dg_40HP_left)/2, dg_offset_x, dg_offset_y, dg_pixel_size, dg_rez_x);
      }
      else if(face_dir == 1)
      {
        render(dg_40HP_middle, sizeof(dg_40HP_middle)/2, dg_offset_x, dg_offset_y, dg_pixel_size, dg_rez_x);
      }
      else if(face_dir == 2)
      {
        render(dg_40HP_right, sizeof(dg_40HP_right)/2, dg_offset_x, dg_offset_y, dg_pixel_size, dg_rez_x);
      }
      else
      {
        render(dg_40HP_middle, sizeof(dg_40HP_middle)/2, dg_offset_x, dg_offset_y, dg_pixel_size, dg_rez_x);
      }
    }
    // DG Health 1 or higher     
    else if(eeprom[4] > 0x0)
    {
      if(face_dir == 0)
      {
        render(dg_20HP_left, sizeof(dg_20HP_left)/2, dg_offset_x, dg_offset_y, dg_pixel_size, dg_rez_x);
      }
      else if(face_dir == 1)
      {
        render(dg_20HP_middle, sizeof(dg_20HP_middle)/2, dg_offset_x, dg_offset_y, dg_pixel_size, dg_rez_x);
      }
      else if(face_dir == 2)
      {
        render(dg_20HP_right, sizeof(dg_20HP_right)/2, dg_offset_x, dg_offset_y, dg_pixel_size, dg_rez_x);
      }
      else
      {
        render(dg_20HP_middle, sizeof(dg_20HP_middle)/2, dg_offset_x, dg_offset_y, dg_pixel_size, dg_rez_x);
      }
    }
    // DG DEAD. HEALTH = 0
    else
    {
      render(dg_dead, sizeof(dg_dead)/2, dg_offset_x, dg_offset_y, dg_pixel_size, dg_rez_x);         
    }
  }
  // DG ANGRY!
  else
  {
    // DG Anger 80 or higher
    if(eeprom[5] >= 0x50)
    {
      if(face_dir == 0)
      {
        render(dg_FullHP_angry_left, sizeof(dg_FullHP_angry_left)/2, dg_offset_x, dg_offset_y, dg_pixel_size, dg_rez_x);
      }
      else if(face_dir == 1)
      {
        render(dg_FullHP_angry_middle, sizeof(dg_FullHP_angry_middle)/2, dg_offset_x, dg_offset_y, dg_pixel_size, dg_rez_x);
      }
      else if(face_dir == 2)
      {
        render(dg_FullHP_angry_right, sizeof(dg_FullHP_angry_right)/2, dg_offset_x, dg_offset_y, dg_pixel_size, dg_rez_x);
      }
      else
      {
        render(dg_FullHP_angry_middle, sizeof(dg_FullHP_angry_middle)/2, dg_offset_x, dg_offset_y, dg_pixel_size, dg_rez_x);
      }
    }
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

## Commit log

2019-06-17 first REV
    [DOOM_SAO.brd, DOOM_SAO.sch, Soldering_Fixture_REV1.skp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]
2019-06-17 updated copyright year
    [DOOM_SAO.brd, DOOM_SAO.sch]
2019-06-28 Readme for Hardware
    [Soldering_Fixture.skp, Soldering_Fixture.stl, Soldering_Fixture_REV1.skp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]
2019-07-17 Code cleanup, isolate eeprom write, fix terminal for returns
    [DOOM_SAO.ino]
2019-07-17 I2C Sniffer implemented!
2019-07-17 tweaked menu selection for i2c sniffer
2019-07-17 Replace "Doom" with "DOOM"
    [DOOM_SAO.ino]
2019-07-17 Updating Solder Fixture for screens
    [Soldering_Fixture.skp, Soldering_Fixture.stl]
2019-07-18 I can't spell Carriage
2019-07-27 Fixing anger and duplicate/incorrect faces.
    [DOOM_SAO.ino]
2019-07-28 Airplane mode to mitigate I2C Address Conflict
    This was discovered due to DaBomb badge LED Driver using same address as our EEPROM

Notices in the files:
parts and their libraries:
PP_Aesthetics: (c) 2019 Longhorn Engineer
